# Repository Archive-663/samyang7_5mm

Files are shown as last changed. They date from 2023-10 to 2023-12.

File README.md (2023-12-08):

# Lot no. 009 | Samyang 7.5mm f3.5 Leica M Rehousing

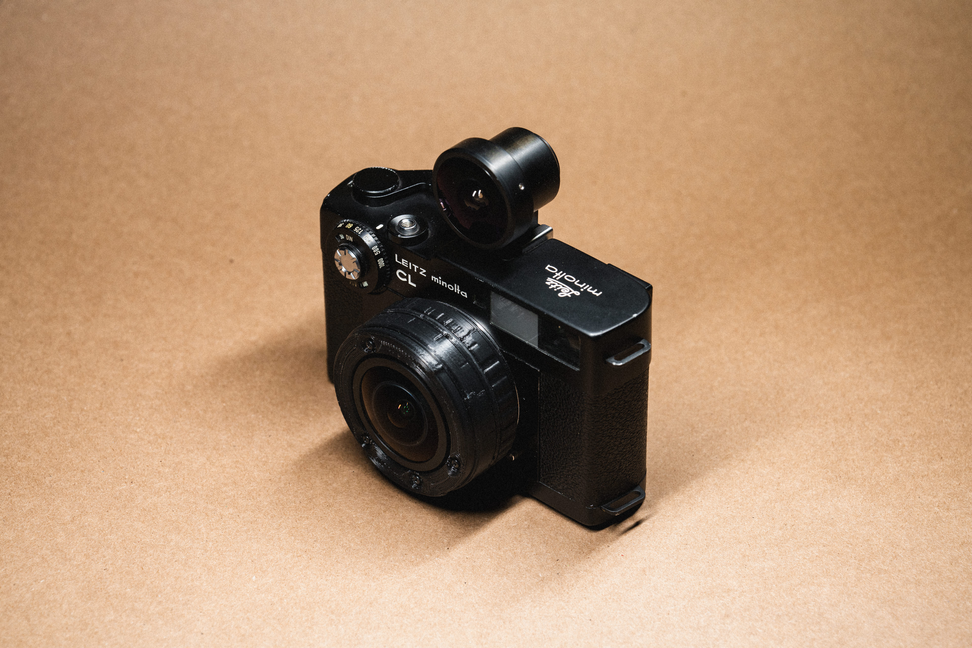
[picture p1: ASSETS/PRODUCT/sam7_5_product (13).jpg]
productShot001


### In this repository:
- [Samyang 7.5mm f3.5 MFT to Leica M Rehousing](https://github.com/Archive-663/samyang7_5mm/tree/main/sam7_5_MFT-LM_rehousing)
- [Circular Fisheye Viewfinder](https://github.com/Archive-663/samyang7_5mm/tree/main/viewFinder)

### Accompanying video:
<a href='https://www.youtube.com/watch?v=sT1oIzzUE1g' target='_blank'>003 / / the one where it feels like I'm going in circles every day forever and there's no escape</a>

### Background Story:
I believe this is the most compact full circular fisheye 135 film setup available. If I'm wrong, please let me know. 

I recently picked up a Minolta CL to design a few things for. When I was looking at the Leica M mount there wasn't a native circular fisheye. This is my attempt to rectify that error. This lens has no coding or focus coupling, but works perfectly well with my Minolta CL. The flange focal distance of the Leica M mount is 27.80mm while the MFT flange focal distance is 19.25mm. This meant that I had to shave off 8.55mm from the Samyang body. Removing the MFT mount wasn't enough so I had to reverse engineedr the focus track and shave off an additional 2-3mm from the focusing track while making sure I didn't interfere with the original functions. Once I verified the function through SLA printing, I sent the focus track to get cnc'ed. Everything else was 3d printed because the core functionality relied on the focus track being correct and the fidelity of FDM printing and even SLA printing isn't great when you want accuracy and strength. 

The problem was creating a viewfinder with off the shelf parts. Now I know what you're thinking, how am I going to solve this problem with no experience with designing optics. Well, it's pretty simple -- smartphone lenses. So, the first idea I had was to see if the fisheye filters for slr lenses would work. And to a certain extent they did, but the size was not acceptable. I assumed these lens filters would work because they don't change the focusing characteristics of the lenses I tried. This is more pronounced on smartphones. I figured the filters would have reletively deep depth of focus and everything would be in focus. So I picked up a cheap generic set of smartphone lenses and freelensed a basic circular fisheye viewfinder. Then 3D printed and repeated until I had an acceptable viewfinder. 

### Help support Archive 663 with a dontation or monthly sub



### Update Notes:
- 2023-12-08: Updated viewfinder assemblies. Added additional Lemuro Fisheye viewfinder body vairiant. 238deg to Death Lens Fisheye name change.

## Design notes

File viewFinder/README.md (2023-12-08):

## ~170 Degree Viewfinder
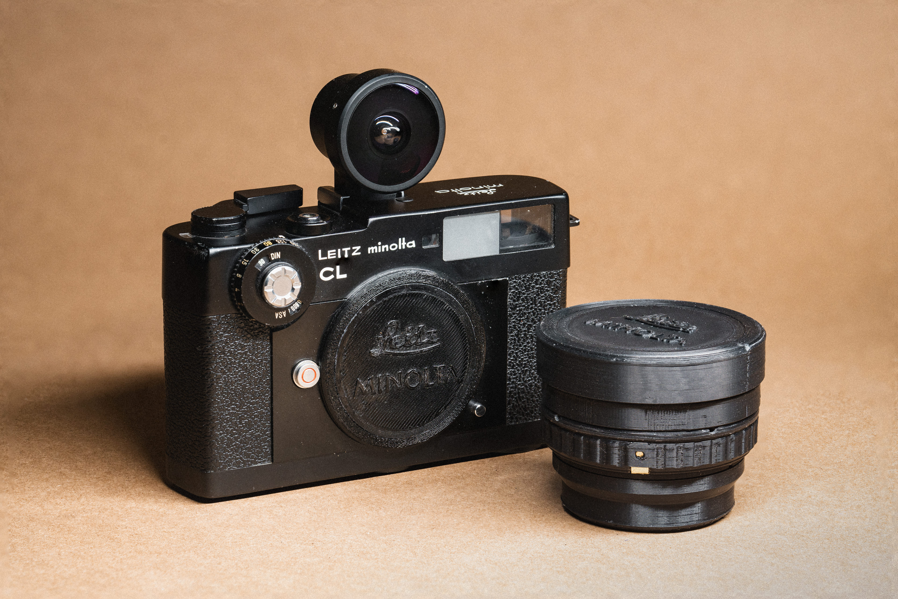
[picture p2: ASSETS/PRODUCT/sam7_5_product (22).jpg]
productShot001


### Features:
- About a 170 Degree Field of View
- Alternate setup offers somewhere in the ball park of +190 Degree Field of View
- Relatively compact
- Off the shelf optics

### What you'll need:

#### For Print
- 4x M2 x 3mm set screws (grub screws) for Standard Viewfinder
- 3x M1.6 x 5mm machine screws (PETG) or self tapping screws (PETG or ABS) for Lemuro and Death Lens
- 2x M3 x 6mm pan head machine screws (PETG) or self tapping screws (PETG or ABS)

#### For CNC
- 3x M2 x 3mm set screws (grub screws)
- 2x M3 x 6mm pan head machine screws

#### Lens Elements
- A set of smartphone lenses that include a 198 Fisheye Lens + 120 Super Wide-Angle Lens
- Similar to this: [Keywing Phone lens kit](https://www.amazon.com/gp/product/B08DQRKY6D/ref=ppx_yo_dt_b_search_asin_title?ie=UTF8&psc=1)
- For a wider FOV you can try finding these:
    - [Deathlens Fisheye](https://www.deathdigital.com/collections/all/products/fisheye-lens-iphone-14) I don't know if they changed their design since I made this viewfinder.
     
	    or    
    - [Lemuro Fisheye](https://www.amazon.co.uk/Lemuro-Fisheye-8mm-Lens-Silver/dp/B07VYL3XXR?ref_=ast_sto_dp&th=1&psc=1) They're no longer in stock with retailers but you can find them on eBay or the like. 

### What would be helpful:
- M1.4 drill bit
- M1.6 tap
- M2 drill bit
- M2 tap
- M3 drill bit
- M3 tap

### Printing help:
Filament recommendation:
- ABS
- PETG

You can reference the supplied 'printOrientation' .3mf files for suggested print orientation.

### Assembly help:
Please view the _assembly.stp file for help in parts orientation. If you do not have a CAD program, <a href="https://www.freecad.org/downloads.php" target="_blank">download FreeCAD</a> to view the assembly file and better understand how it should assemble.

Drill out M1.6 holes to 1.4mm before tapping with the M1.6 tap. 

The viewfinder can be completely done with FDM 3D printing. If you want a better fit and finish send the 'forCNC' STP/STEP files to get machined. Depending on what you print you'll need to secure the front element with 3-4 M2 set screws. There are two coldshoe sizes and you can use either for the standard ~170 viewfinder. They secure with M3 machine screws.

The optics needed are from the 198 Degree fisheye lens and the 120 degree wide angle lens. Please refer to the supplied assembly STP file to see their orientation. For the wider FOV viewfinder you need to locate a Deathlens fisheye lens or a Lemuro fisheye lens. Again please refer to the _assembly.stp file for lens orientation. if using FreeCAD, the naming conventions should carry over and you will be able to see which lens element you need from the various smartphone lenses. (Verified in FreeCAD 0.18) If using something like Solid Edge open the file as an assembly to retain the names of the parts.

### Help support Archive 663 with a dontation or monthly sub



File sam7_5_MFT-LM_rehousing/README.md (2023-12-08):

## Samyang 7.5mm f3.5 Leica M Rehousing

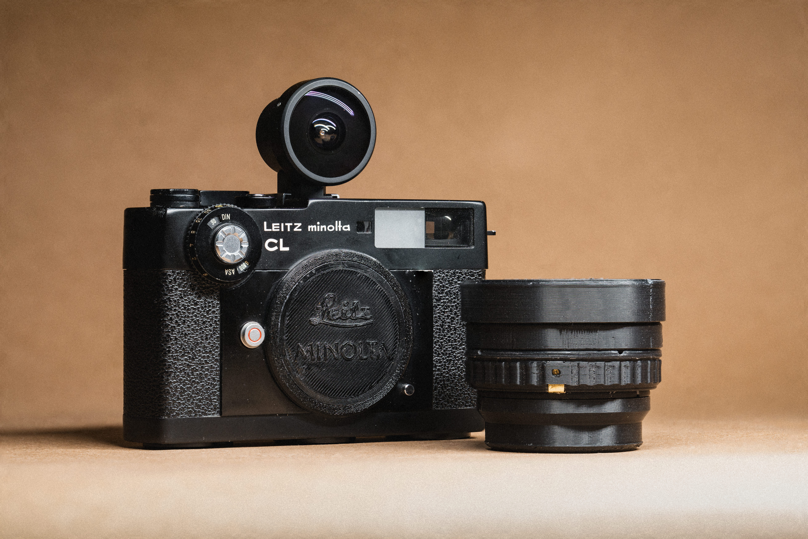
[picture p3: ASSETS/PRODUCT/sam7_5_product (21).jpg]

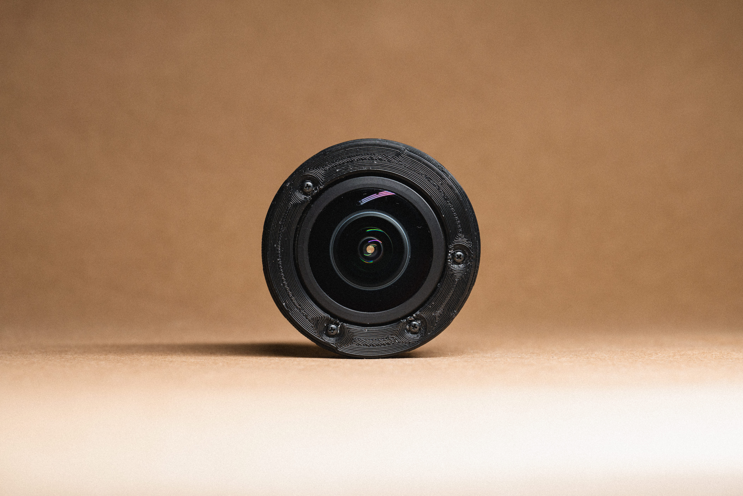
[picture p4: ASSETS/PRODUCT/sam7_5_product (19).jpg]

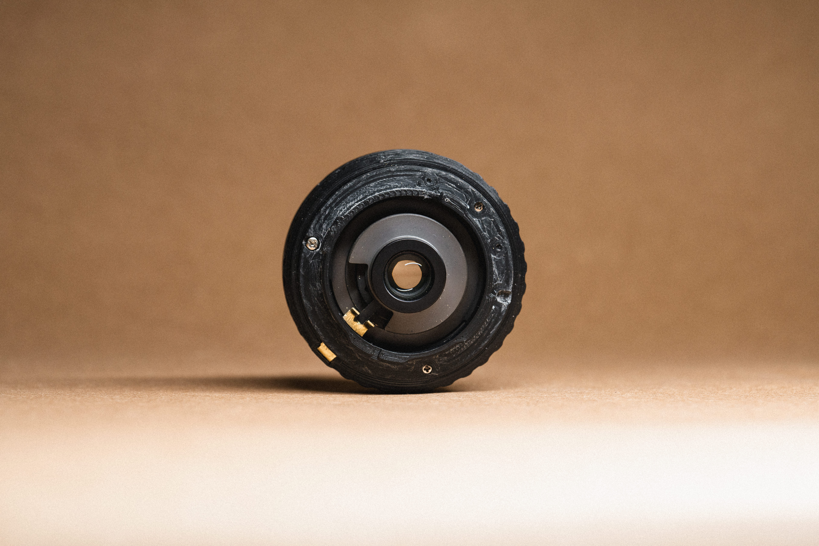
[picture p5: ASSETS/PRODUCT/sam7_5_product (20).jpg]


### Features:
- The most compact full circular fisheye lens for any 135 film interchangable camera system. 
- Redesigned Focus Track to allow for infinity focus
- Customizeable Focus, Aperture, and Indicator Rings

### What you'll need:
- 7 x M1.7 x 5mm Pan Head Machine Screw
- 1 x M2 x 3mm set screw (grub screw)
- ~50mm x 12mm x 0.5mm brass bar/sheet
- 1.5mm x 2mm spring
- 1.5mm ball bearing

### What would be helpful:
- M2 drill bit
- M2 tap
- A Dremel w/cutoff wheel
- Microfiles

### Printing help:
Filament recommendation:
- ABS
- PETG

You can reference the supplied 'printOrientation' .3mf files for suggested print orientation.

### Assembly help:
Please view the _assembly.stp file for help in parts orientation. If you do not have a CAD program, <a href="https://www.freecad.org/downloads.php" target="_blank">download FreeCAD</a> to view the assembly file and better understand how it should assemble.

I don't recommend you use a 3D printed focus track. Send the STP/STEP file off to get CNC'ed for you. Request they tap the holes for M1.7 threads. There is a hold on the cylinder that is for a 1.5mm spring and ball bearing that acts as the aperture detent. You may need to fine tune fitment after wards.

THe indicator ring works better if you tap the threads with an M2 thread first. Since it's using set screws it'll expand the ring diameter, so you'll have to file the interior mating focus ring to make it rotate smoothly. 

THe aperture arm should not be used if printed. Use it as an example of how your aperture arm should look. Transfer the template file onto 0.5mm brass. Cut to template line. Fold on template divots. Sand until fitment is correct. Install and mark the hole from the aperture ring. Drill the hole and secure with an M2 x 3mm set screw.

For the lens cap, use some sort of glue to join the nameplate and lens cap. I used superglue or cyanoacrylate. If you do just make sure the curing process is completed. I've had bad experiences with superglue offgassing and fogging lenses. 

### Help support Archive 663 with a dontation or monthly sub



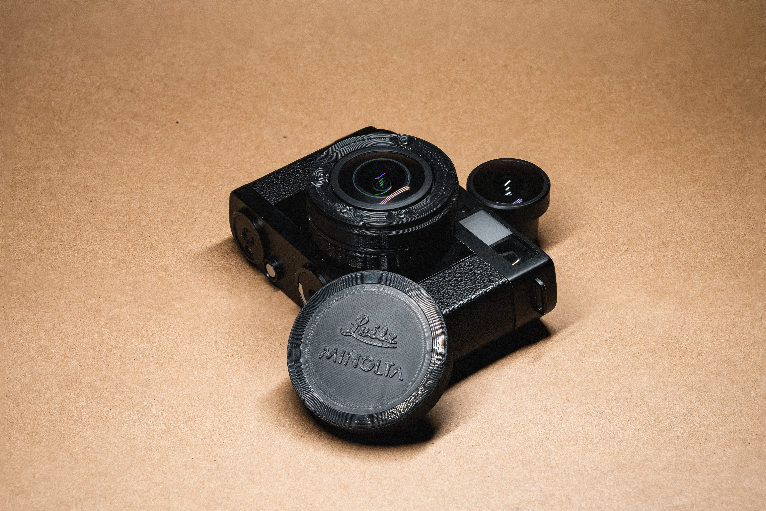
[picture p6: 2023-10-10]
ASSETS/PRODUCT/sam7_5_product (15).jpg

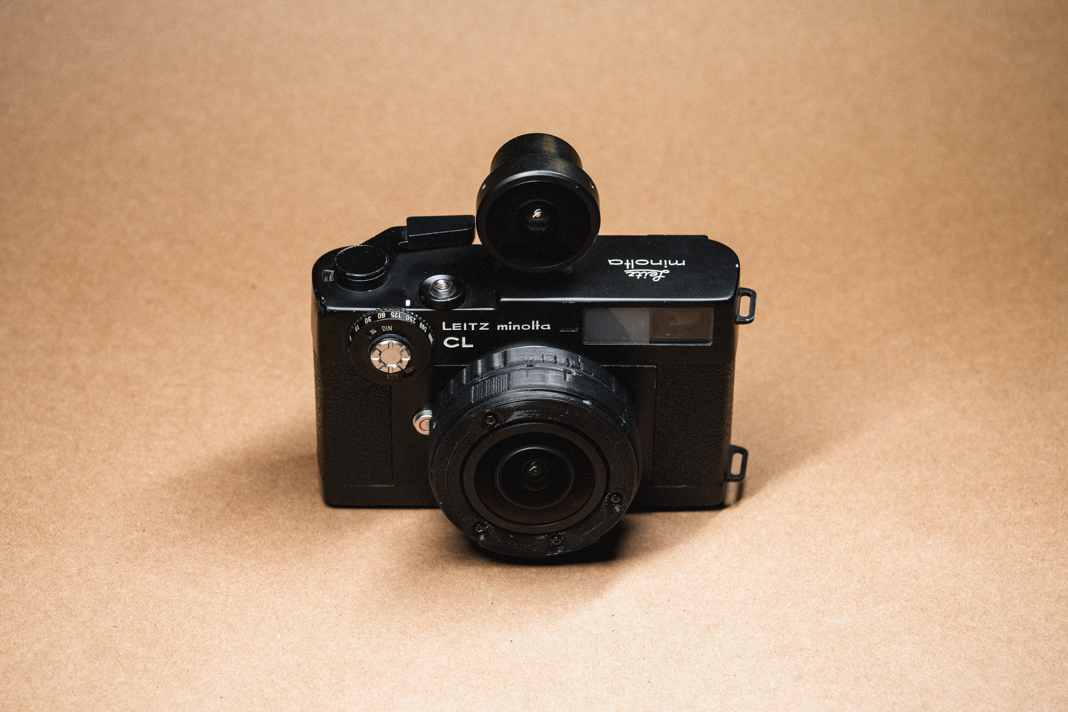
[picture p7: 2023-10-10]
ASSETS/PRODUCT/sam7_5_product (12).jpg

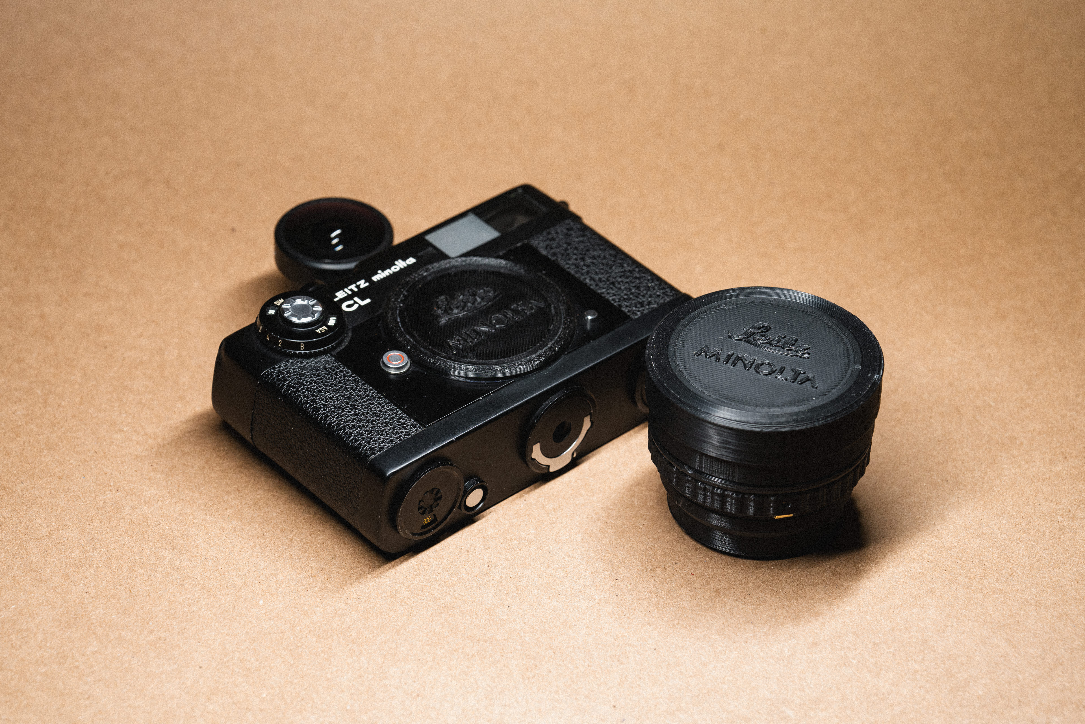
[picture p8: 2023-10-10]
ASSETS/PRODUCT/sam7_5_product (16).jpg

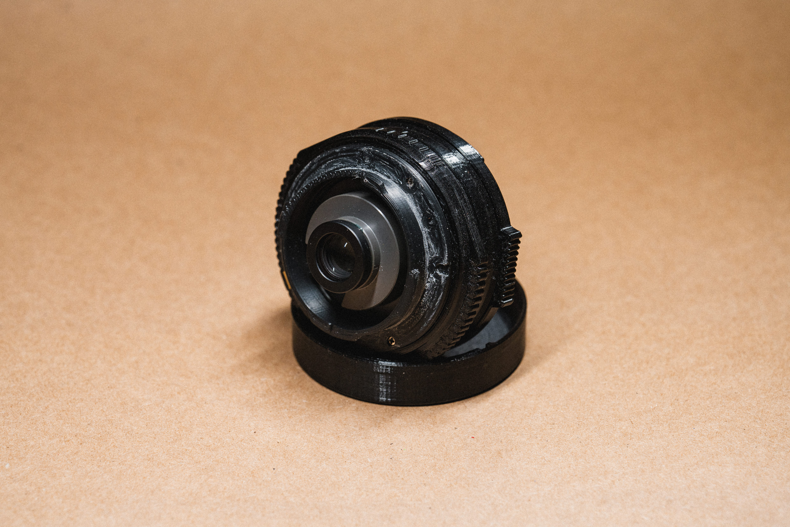
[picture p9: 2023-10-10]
ASSETS/PRODUCT/sam7_5_product (6).jpg

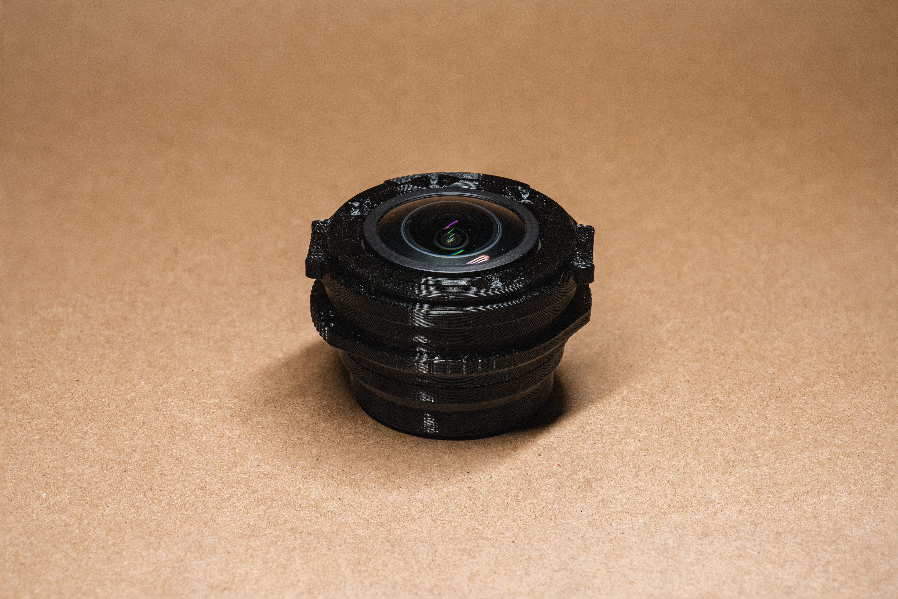
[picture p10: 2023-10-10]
ASSETS/PRODUCT/sam7_5_product (8).jpg

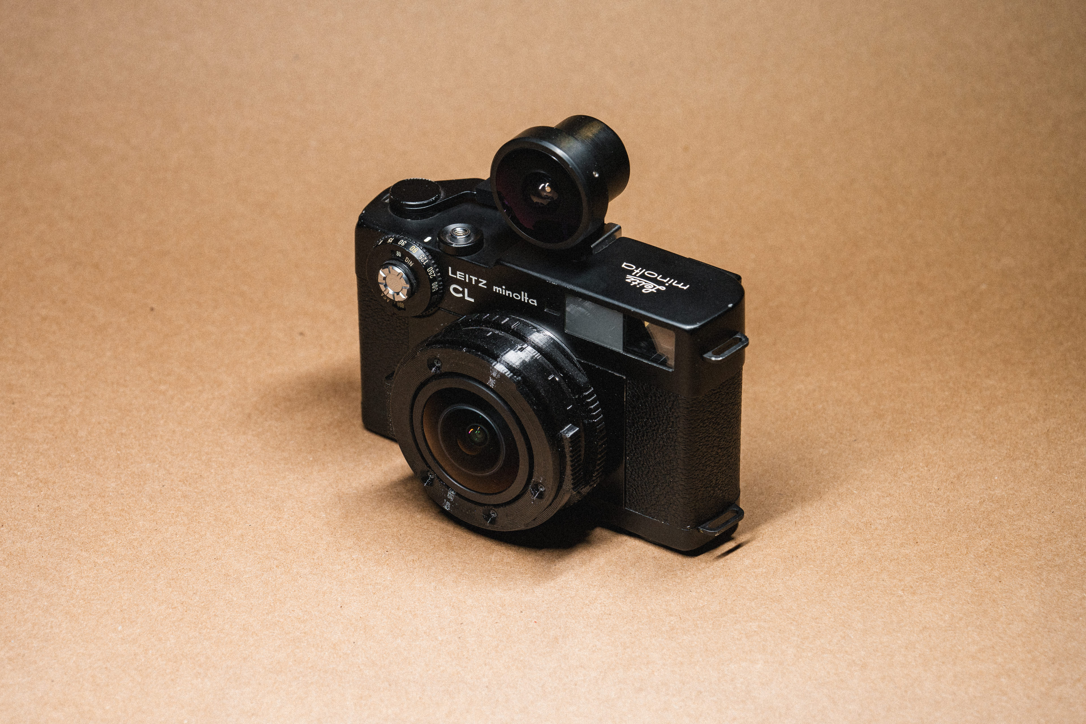
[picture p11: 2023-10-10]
ASSETS/PRODUCT/sam7_5_product (0).jpg

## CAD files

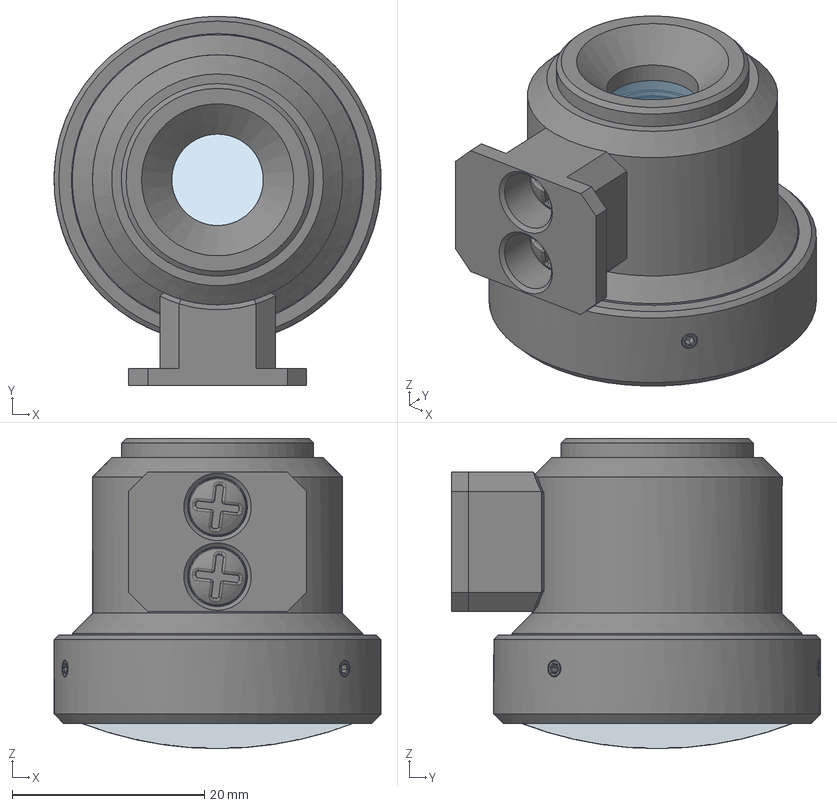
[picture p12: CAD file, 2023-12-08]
viewFinder/STEP/Death Lens Fisheye/forCNC/sam7_5_viewFinder_deathLensFisheye_forCNC_assembly.stp
34.0 x 38.4 x 32.3 mm
sam7_5_MFT-LM_viewFinderBody_deathLensFisheye_forCNC
sam7_5_MFT-LM_viewFinder_deathLensFisheye_frontGlassElement
M3_panHead_6mm x 2
sam7_5_MFT-LM_viewFinderCollar_deathLensFisheye_-1mm
sam7_5_MFT-LM_viewFinder_120deg_rearGlassElement
sam7_5_MFT-LM_viewFinderCap_deathLensFisheye_forCNC
sam7_5_MFT-LM_viewFinderColdShoe_deathLensFisheye_forCNC
sam7_5_MFT-LM_viewFinder_120deg_frontGlassElement
sam7_5_MFT-LM_viewFinder_198deg_middleGlassElement
M2_setScrew_3mm x 3

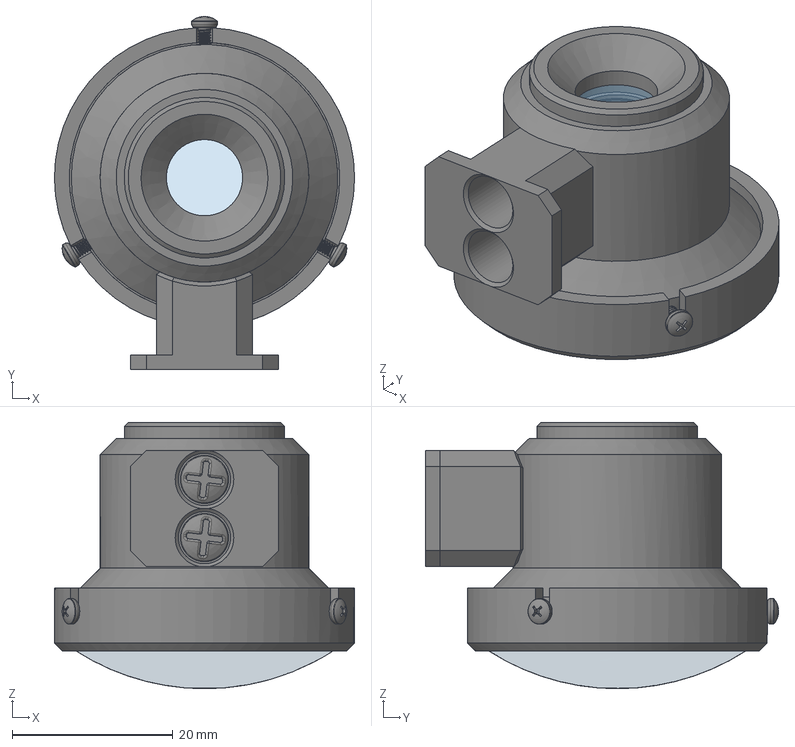
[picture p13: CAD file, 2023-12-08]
viewFinder/STEP/Lemuro Fisheye/forPrint/sam7_5_viewFinder_lemuroFisheye_forPrint_assembly.stp
37.4 x 44.0 x 33.2 mm
sam7_5_MFT-LM_viewFinder_198deg_frontGlassElement
M1.6_panHead_5mm x 3
sam7_5_MFT-LM_viewFinder_lemuroFisheye_frontGlassElement
M3_panHead_6mm x 2
sam7_5_MFT-LM_viewFinderCollar_deathLensFisheye_-1mm
sam7_5_MFT-LM_viewFinder_120deg_rearGlassElement
sam7_5_MFT-LM_viewFinder_198deg_middleGlassElement
sam7_5_MFT-LM_viewFinderColdShoe_lemuroFisheye_forPrint
sam7_5_MFT-LM_viewFinderCap_lemuroFisheye_forPrint
sam7_5_MFT-LM_viewFinderBody_lemuroFisheye_forPrint

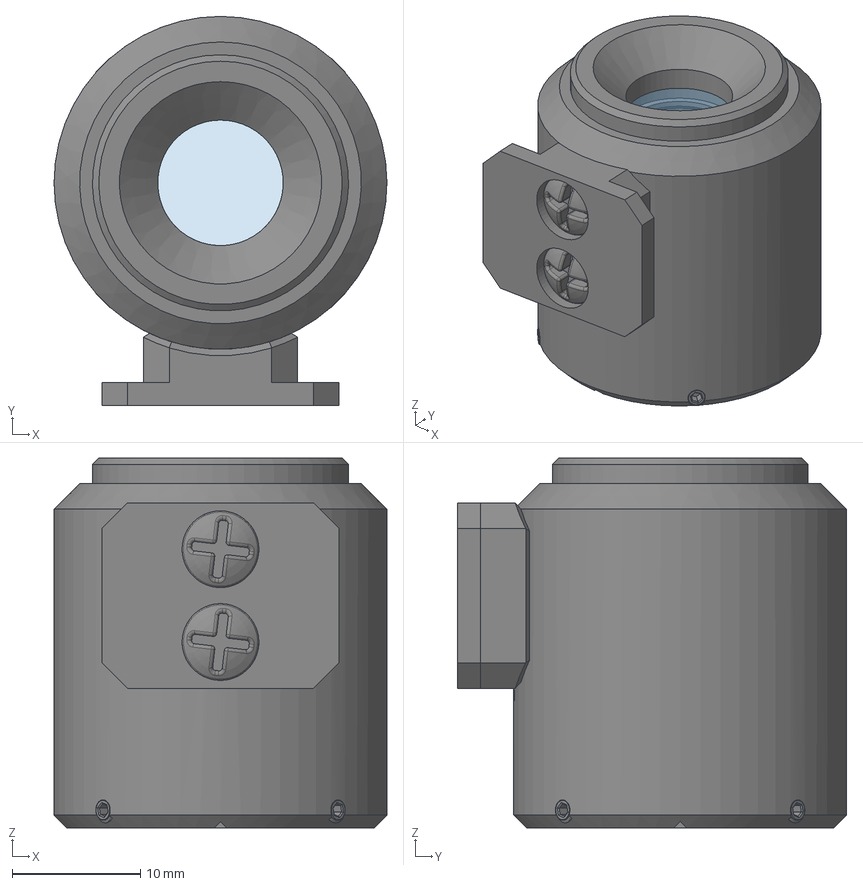
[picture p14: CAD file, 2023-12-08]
viewFinder/STEP/Standard/sam7_5_viewFinder_standard_assembly.stp
26.0 x 30.4 x 28.9 mm
M2_setScrew_3mm x 4
sam7_5_MFT-LM_viewFinderCollar_deathLensFisheye_-1mm
sam7_5_MFT-LM_viewFinder_120deg_rearGlassElement
sam7_5_MFT-LM_viewFinderBody_standard
sam7_5_MFT-LM_viewFinder_120deg_frontGlassElement
sam7_5_MFT-LM_viewFinder_198deg_middleGlassElement
sam7_5_MFT-LM_viewFinderColdShoe
sam7_5_MFT-LM_viewFinder_198deg_frontGlassElement
M3_panHead_6mm x 2

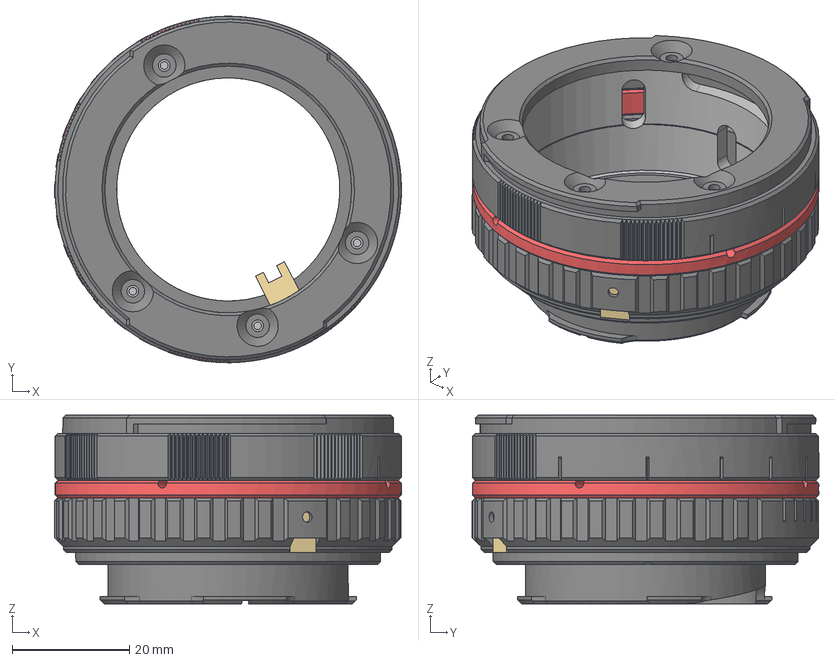
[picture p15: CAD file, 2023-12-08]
sam7_5_MFT-LM_rehousing/STEP/sam7_5_MFT-LM_assembly.stp
59.1 x 59.0 x 32.1 mm
sam7_5_MFT-LM_mount_LM
sam7_5_MFT-LM_focusTrack_LM_forCNC
sam7_5_MFT-LM_indicatorRing
sam7_5_MFT-LM_apertureRing
sam7_5_MFT-LM_focusRing
sam7_5_MFT-LM_faceplate
sam7_5_MFT-LM_apertureArm

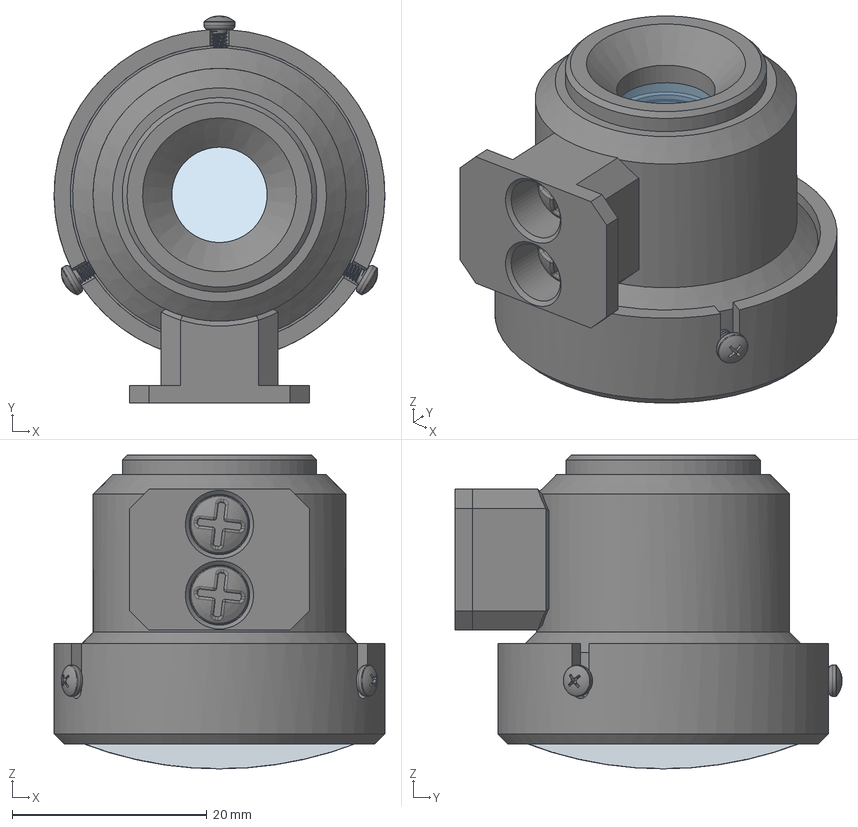
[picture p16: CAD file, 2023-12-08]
viewFinder/STEP/Death Lens Fisheye/forPrint/sam7_5_viewFinder_deathLensFisheye_forPrint_assembly.stp
34.0 x 39.8 x 32.3 mm
sam7_5_MFT-LM_viewFinderCap_deathLensFisheye_forPrint
sam7_5_MFT-LM_viewFinderBody_deathLensFisheye_forPrint
sam7_5_MFT-LM_viewFinderColdShoe_deathLensFisheye_forPrint
sam7_5_MFT-LM_viewFinder_deathLensFisheye_frontGlassElement
M3_panHead_6mm x 2
sam7_5_MFT-LM_viewFinderCollar_deathLensFisheye_-1mm
sam7_5_MFT-LM_viewFinder_120deg_rearGlassElement
sam7_5_MFT-LM_viewFinder_120deg_frontGlassElement
sam7_5_MFT-LM_viewFinder_198deg_middleGlassElement
M1.6_panHead_5mm x 3

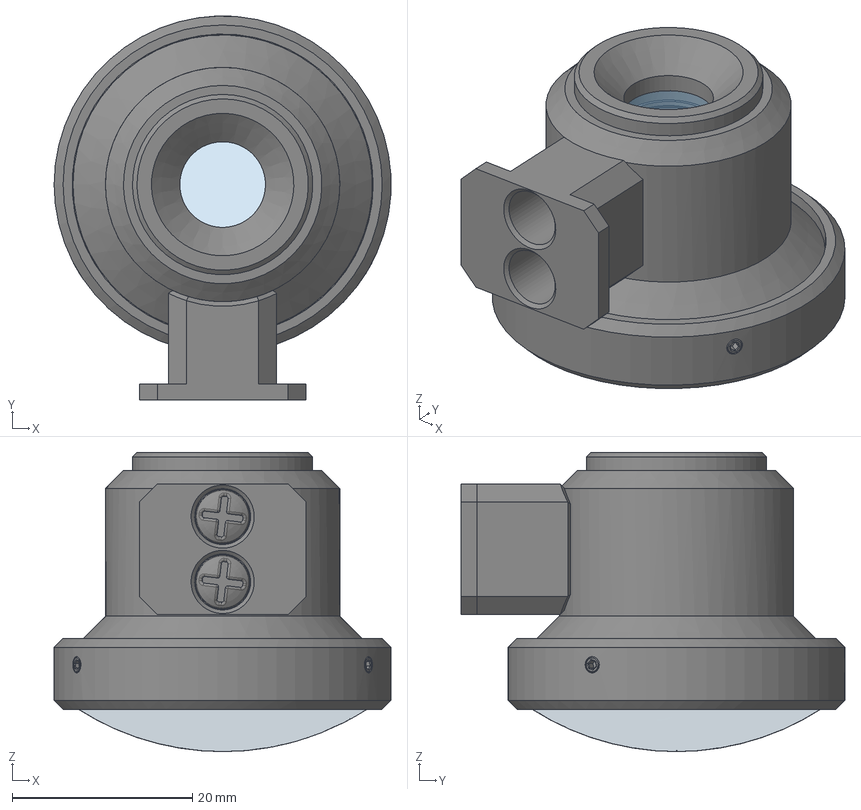
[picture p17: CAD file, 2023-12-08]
viewFinder/STEP/Lemuro Fisheye/forCNC/sam7_5_viewFinder_lemuroFisheye_forCNC_assembly.stp
37.4 x 42.6 x 33.2 mm
sam7_5_MFT-LM_viewFinder_198deg_frontGlassElement
M2_setScrew_3mm x 3
sam7_5_MFT-LM_viewFinder_lemuroFisheye_frontGlassElement
M3_panHead_6mm x 2
sam7_5_MFT-LM_viewFinderCollar_deathLensFisheye_-1mm
sam7_5_MFT-LM_viewFinder_120deg_rearGlassElement
sam7_5_MFT-LM_viewFinder_198deg_middleGlassElement
sam7_5_MFT-LM_viewFinderColdShoe_lemuroFisheye_forCNC
sam7_5_MFT-LM_viewFinderCap_lemuroFisheye_forCNC
sam7_5_MFT-LM_viewFinderBody_lemuroFisheye_forCNC

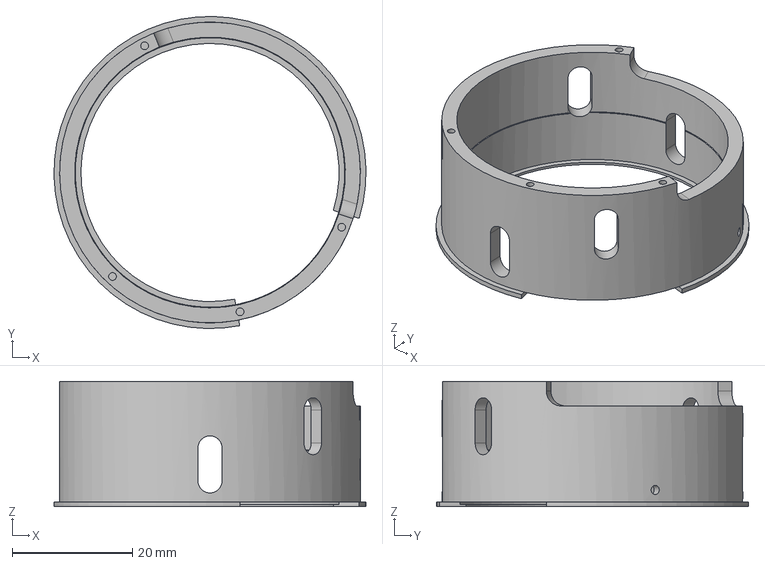
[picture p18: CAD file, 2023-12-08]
sam7_5_MFT-LM_rehousing/STEP/sam7_5_MFT-LM_focusTrack_LM_forCNC.stp
52.0 x 52.0 x 20.9 mm

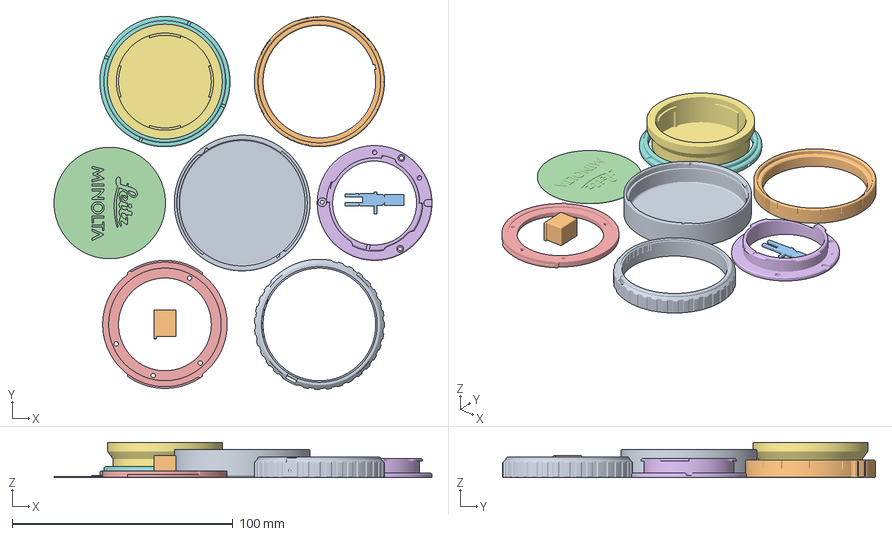
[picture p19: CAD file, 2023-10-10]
sam7_5_MFT-LM_rehousing/STL/printOrientation_sam7_5_MFT-LM.3mf
171.2 x 169.0 x 16.0 mm
sam7_5_MFT-LM_lensCap.stl
sam7_5_MFT-LM_apertureArmBuck.stl
sam7_5_MFT-LM_apertureArmTemplate.stl
sam7_5_MFT-LM_lensCapNameplate.stl
sam7_5_MFT-LM_faceplate.stl
sam7_5_MFT-LM_mount_LM.stl
sam7_5_MFT-LM_rearCap_LM.stl
sam7_5_MFT-LM_indicatorRing.stl
sam7_5_MFT-LM_apertureRing.stl
sam7_5_MFT-LM_focusRing.stl

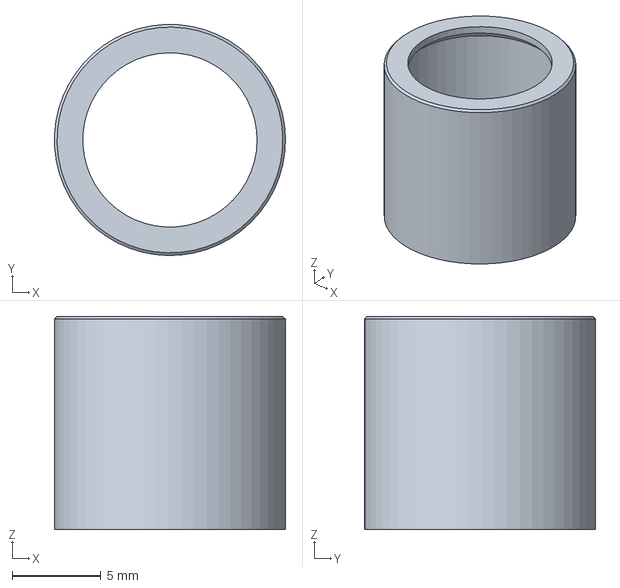
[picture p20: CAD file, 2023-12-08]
viewFinder/STEP/Death Lens Fisheye/forCNC/sam7_5_viewFinder_collar_glassElement.stp
13.0 x 13.0 x 12.0 mm

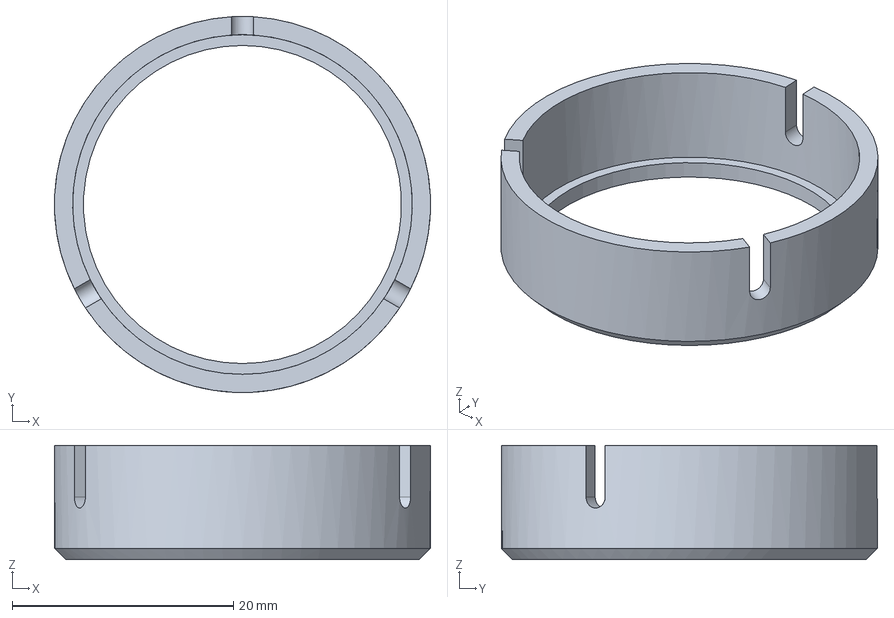
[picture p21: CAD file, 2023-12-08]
viewFinder/STEP/Death Lens Fisheye/forPrint/sam7_5_viewFinderCap_deathLensFisheye_forPrint.stp
34.0 x 34.0 x 10.3 mm

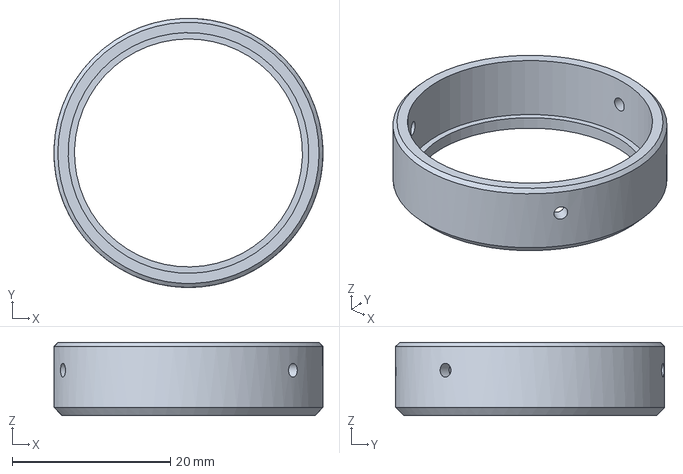
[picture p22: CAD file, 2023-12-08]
viewFinder/STEP/Lemuro Fisheye/forCNC/sam7_5_viewFinderCap_deathLensFisheye_forCNC.stp
34.0 x 34.0 x 9.23 mm

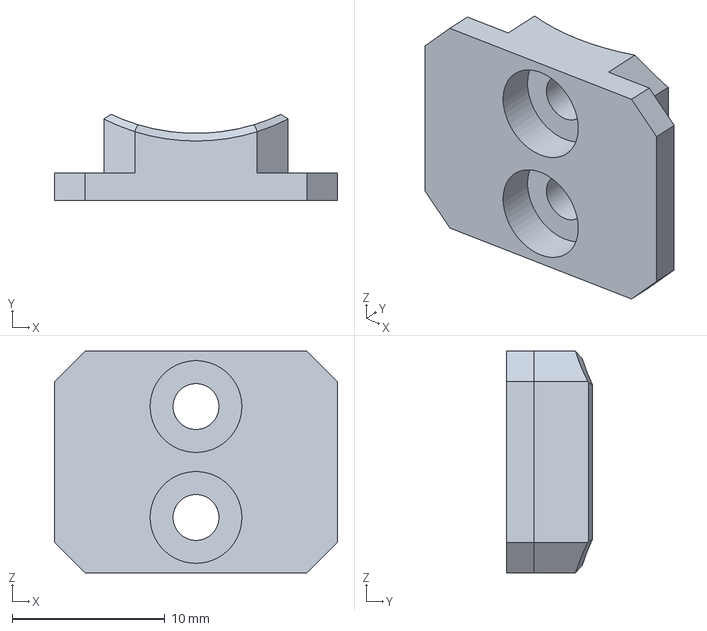
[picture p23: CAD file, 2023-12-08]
viewFinder/STEP/Standard/sam7_5_viewFinderColdShoe.stp
18.5 x 5.64 x 14.5 mm

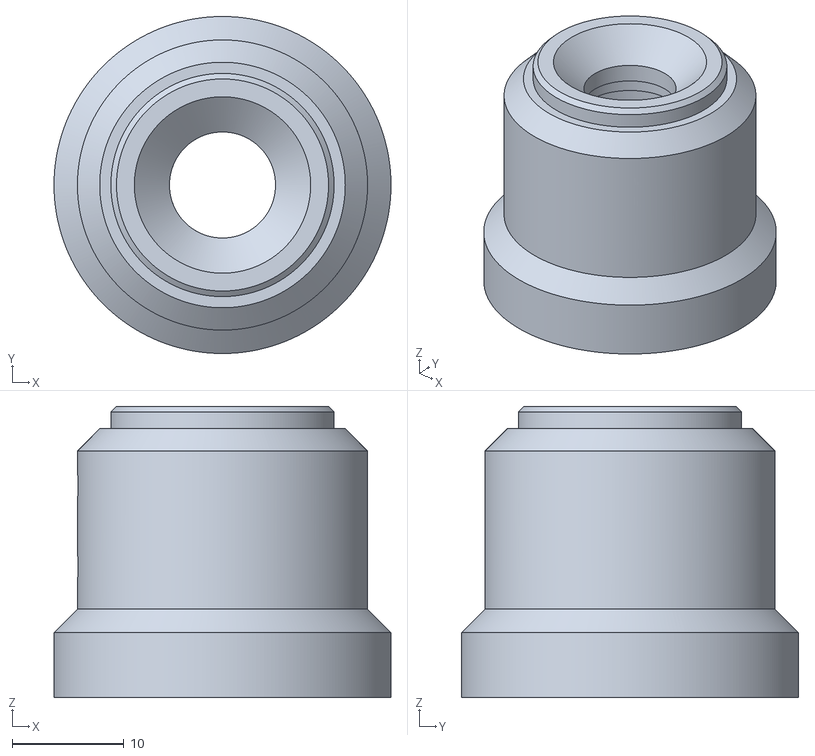
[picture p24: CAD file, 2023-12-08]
viewFinder/STL/Death Lens Fisheye/forCNC/sam7_5_MFT-LM_viewFinderBody_deathLensFisheye_forCNC.stl
30.2 x 30.2 x 26.1

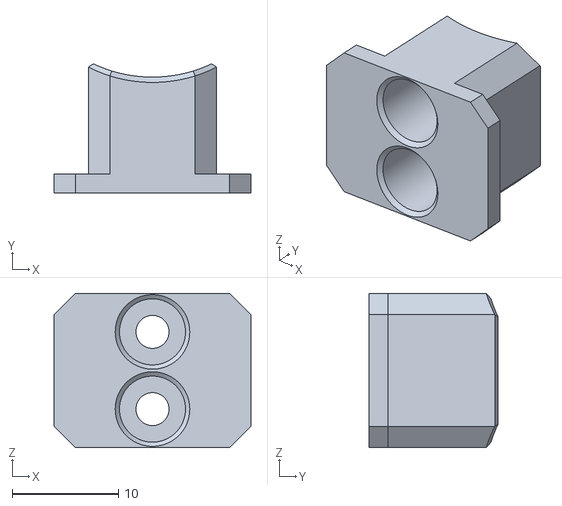
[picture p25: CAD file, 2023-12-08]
viewFinder/STL/Lemuro Fisheye/forCNC/sam7_5_MFT-LM_viewFinderColdShoe_lemuroFisheye_forCNC.stl
18.5 x 12.1 x 14.5

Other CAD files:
viewFinder/STL/Death Lens Fisheye/forPrint/sam7_5_MFT-LM_viewFinderCap_deathLensFisheye_forPrint.stl
viewFinder/STL/Lemuro Fisheye/forPrint/sam7_5_MFT-LM_viewFinderCap_lemuroFisheye_forPrint.stl
viewFinder/STL/Standard/sam7_5_MFT-LM_viewFinderColdShoe.stl
sam7_5_MFT-LM_rehousing/STEP/sam7_5_MFT-LM_apertureArm.stp
sam7_5_MFT-LM_rehousing/STEP/sam7_5_MFT-LM_apertureArmBuck.stp
sam7_5_MFT-LM_rehousing/STEP/sam7_5_MFT-LM_apertureArmTemplate.stp
sam7_5_MFT-LM_rehousing/STEP/sam7_5_MFT-LM_apertureRing.stp
sam7_5_MFT-LM_rehousing/STEP/sam7_5_MFT-LM_facePlate.stp
sam7_5_MFT-LM_rehousing/STEP/sam7_5_MFT-LM_focusRing.stp
sam7_5_MFT-LM_rehousing/STEP/sam7_5_MFT-LM_indicatorRing.stp
sam7_5_MFT-LM_rehousing/STEP/sam7_5_MFT-LM_lensCap.stp
sam7_5_MFT-LM_rehousing/STEP/sam7_5_MFT-LM_lensCapNameplate.stp
sam7_5_MFT-LM_rehousing/STEP/sam7_5_MFT-LM_mount_LM.stp
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

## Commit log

2023-10-10 Create Repo
    [printOrientation_sam7_5_MFT-LM.3mf, printOrientation_sam7_5_MFT-LM_viewFinderBody_238_forPrint.3mf, printOrientation_sam7_5_MFT-LM_viewFinder_STD.3mf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]
2023-10-10 rearranged filed
    [printOrientation_sam7_5_MFT-LM.3mf, printOrientation_sam7_5_MFT-LM_viewFinderBody_238_forPrint.3mf, printOrientation_sam7_5_MFT-LM_viewFinder_STD.3mf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]
2023-10-11 replace stl in step folder with step
    [sam7_5_MFT-LM_apertureArm.stl, sam7_5_MFT-LM_apertureArmBuck.stl, sam7_5_MFT-LM_apertureArmTemplate.stl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]
2023-10-11 updated files
    [sam7_5_MFT-LM_apertureArm.stp, sam7_5_MFT-LM_apertureArmBuck.stp, sam7_5_MFT-LM_apertureArmTemplate.stp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]
2023-12-08 Updated STP Files
    Cleaned up viewfinder designs and added more specific naming conventions to make assembly understandable.
    [printOrientation_sam7_5_MFT-LM_viewFinderBody_238_forPrint.3mf, printOrientation_sam7_5_MFT-LM_viewFinder_STD.3mf, sam7_5_MFT-LM_apertureArm.stp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]
